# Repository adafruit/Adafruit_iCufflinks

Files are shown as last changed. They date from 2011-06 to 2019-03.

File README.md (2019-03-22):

# iCufflinks

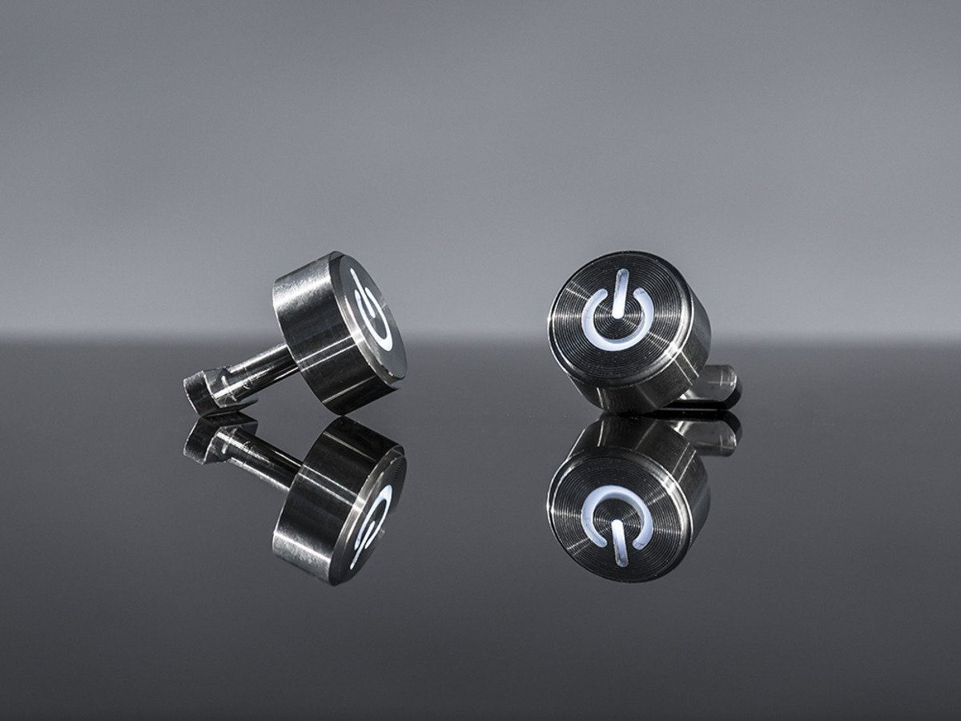
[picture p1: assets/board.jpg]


Sophisticated. Modern. Open Source. Gorgeously machined aluminum with a subtle pulsating LED. Perfect for Father's day or for that geek who loves technology and needs to get dressed up for a special event. Welcome to the future!

This is a new type of product for Adafruit, we want to create wearable electronics that are subtle, fun to wear and look classy. We started with cufflinks and now have a [necklace version](http://www.adafruit.com/products/440) available too.

The cufflinks are CNC machined from the finest 6 series aluminum for durability and beauty. The iCufflinks are a remarkable accessory. Machined with a "screw in backing". Each iCufflink contains a circuit board with pulsating LED and battery.

### Reverse engineered
The "pulsing" is similar to the "breathing" LED pattern on many laptop and computer systems. The default pattern is [reverse engineered](http://www.adafruit.com/blog/2010/08/26/reverse-engineering-the-mac-breathing-led-2/) from the Apple "breathing" LED on Macs, MacBooks, iMacs, etc.

### Open source
Cufflinks are completely open source. [The source code, circuit board files, schematics and CAD files are posted on GitHub. Mod & Hack away! Cufflinks can be reprogrammed to any pattern you'd like!](https://github.com/adafruit/iCufflinks).

### Ready to go
Before your fancy event, just pop the battery in, screw the backing and your iCufflinks will gently pulsate for up to 72 hours. Each order comes with 2 sets of batteries, simply replace them when the LED is too dim to see. We sell replacement batteries as well.

### Designed and made in North America
Cufflinks are lovingly machined in Toronto, Canada by Ross + Doell, assembled in New York, New York USA. Created by Mike Doell, Limor Fried and Phillip Torrone.

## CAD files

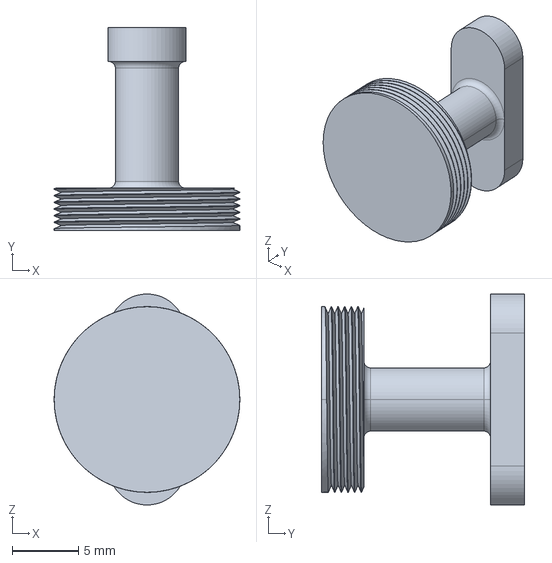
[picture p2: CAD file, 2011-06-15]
CAD/cufflink_back_02.stp
14.0 x 15.2 x 15.9 mm

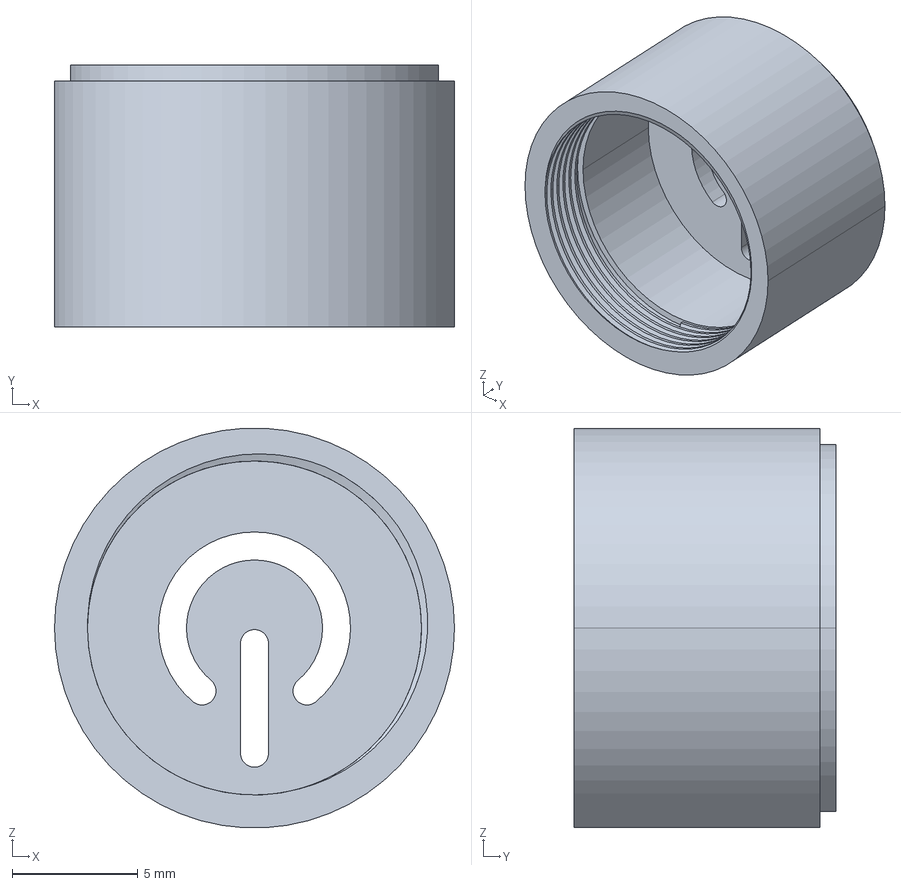
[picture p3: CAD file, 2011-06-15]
CAD/cuffllink_bezel_01.stp
15.9 x 10.4 x 15.9 mm

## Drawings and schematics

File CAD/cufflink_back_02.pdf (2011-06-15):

.55

# SCALE 1.000

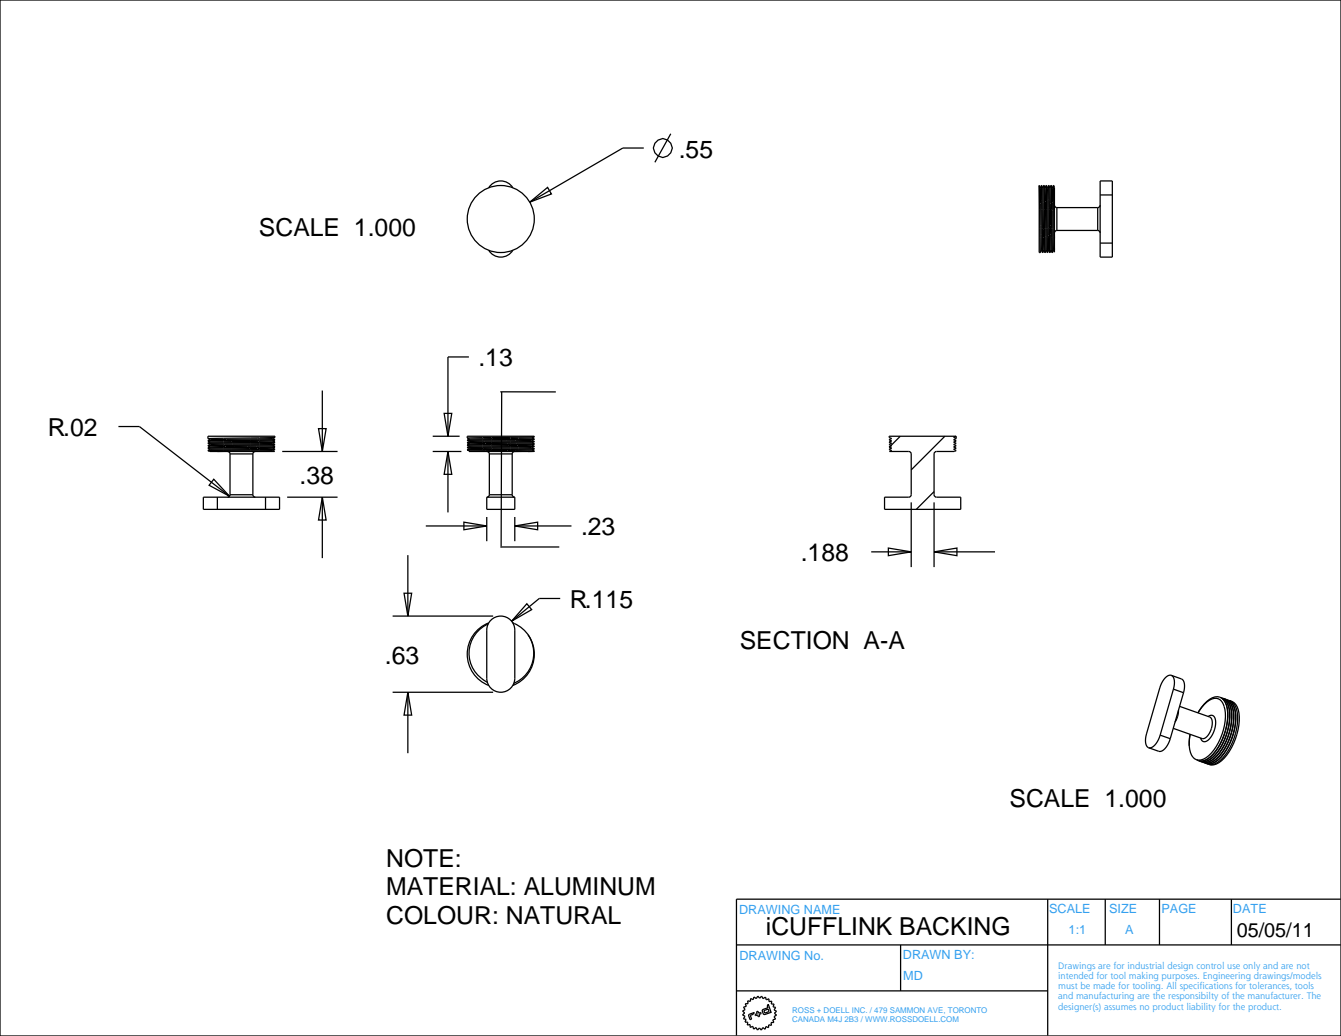
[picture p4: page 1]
NOTE: MATERIAL: ALUMINUM COLOUR: NATURAL; SCALE 1.000; SECTION A-A

DRAWING NAME iCUFFLINK BACKING | SCALE 1:1 | SIZE A | PAGE | DATE 05/05/11

DRAWING No. | DRAWN BY: MD | Drawings are for industrial design control use only and are not intended for tool making purposes. Engineering drawings/models must be made for tooling. All specifications for tolerances, tools and manufacturing are the responsibilty of the manufacturer. The designer(s) assumes no product liability for the product.

ROSS + DOELL INC. / 479 SAMMON AVE, TORONTO
CANADA M4J 2B3 / WWW.ROSSDOELL.COM

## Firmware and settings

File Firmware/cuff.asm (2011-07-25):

.include "tn4def.inc"

.equ    LED = 0				; LED connected to PB0

.cseg
.org 0x0000
	rjmp RESET
.org 0x0008
	rjmp WDT

.def	temp   		= R16	; general purpose temp

RESET:
	sbi DDRB, LED ; LED output
	sbi PORTB, LED ; LED off

	; setting all pullups on unused pins (for power savings)
	; would having them all be outputs use less power?
	ldi temp, (1<<PUEB3)|(1<<PUEB2)|(1<<PUEB1)
	out PUEB, temp

	; changing clock prescale to slow down the processing power 
	; (for power savings)
	; this affects the PWM frequency so if you go too low
	; it may look a little flickery.
	ldi		temp, 0xD8		; write signature
	out		CCP, temp
	; scale to divide by 32. So 8Mhz -> 256kHz
	ldi temp, (0<<CLKPS3)|(1<<CLKPS2)|(0<<CLKPS1)|(1<<CLKPS0) 
	out		CLKPSR, temp

	; set up fast PWM output timer WGM[3:0] = 0101
	; COM0A1 = 1, COM0A0 = 0 or 1
	ldi temp, 0xC1			; Fast PWM (PB2 output)
	out TCCR0A, temp
	ldi temp, 0x81			; fastest clock
	out TCCR0B, temp

	; we dont use the top of the counter since its only 8 bit
	ldi temp, 0
	out OCR0AH, temp

	; enable sleep mode
	ldi temp, (1<<SE) ; by default the mode is 000 Idle
	out SMCR, temp

	sei		; enable global interrupts

LOOPSTART:

	; This is start of Code in Tiny4/5/9/10 (0x4000)
	ldi ZH,	high(SINETAB*2) + 0x40 
	ldi ZL, low (SINETAB*2) ; init Z-pointer to storage bytes
LOOP:
	ld		temp, Z+ ; load next led brightness
	cpi		temp, 0			; last entry?
	brne	NORELOAD
    rjmp    LOOPSTART

NORELOAD:
	out OCR0AL, temp ; Shove the brightness into the PWM driver

	; we want to sleep 6k cycles to match the timing so sleep twice!
	ldi temp, 0xD8		; write signature
	out CCP, temp
	; set watchdog in interrupt mode and 2k cycles
	ldi temp, (0<<WDE)|(1<<WDIE)
	out WDTCSR, temp

	; reset the watchdog timer to full value and sleep until it pops an interrupt
	wdr
	sleep

	ldi temp, 0xD8		; write signature
	out CCP, temp
	; set watchdog in interrupt mode and 4k cycles
	ldi temp, (0<<WDE)|(1<<WDIE)|(1<<WDP0) 
	out WDTCSR, temp

	; reset the watchdog timer to full value and sleep until it pops an interrupt
	wdr
	sleep

	rjmp	LOOP

; this is a do nothing interrupt handler for the watchdog interrupt
WDT:
	reti

SINETAB:
.db 1, 1, 2, 3, 5, 8, 11, 15, 20, 25, 30, 36, 43, 49, 56, 64, 72, 80, 88, 97, 105, 114, 123, 132, 141, 150, 158, 167, 175, 183, 191, 199, 206, 212, 219, 225, 230, 235, 240, 244, 247, 250, 252, 253, 254, 255, 254, 253, 252, 250, 247, 244, 240, 235, 230, 225, 219, 212, 206, 199, 191, 183, 175, 167, 158, 150, 141, 132, 123, 114, 105, 97, 88, 80, 72, 64, 56, 49, 43, 36, 30, 25, 20, 15, 11, 8, 5, 3, 2, 1, 0

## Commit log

2011-06-15 First commit of release!
    [cuff.brd, cuff.sch]
2011-06-15 initial commit of cad STEP files
    [cufflink_back_02.stp, cuffllink_bezel_01.stp]
2011-07-18 This is a test of using the watchdog timer as an interrupt instead of the CPU counter loop for the delay between PWM value switches. This is not tested as I don't have a ATTiny4 to play with but it c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
2011-07-19 enable global interrupts
2011-07-22 removed the unused delay variables that I forgot to take out on the last commit. Adding in two more power savings tricks.
2011-07-24 low power version (integrates commits of @scott-42)
2011-07-24 Revert "changed the clock divider to 64 so now running at 128kHz"
    This reverts commit e72e54e11c92a2d4368831213a4a51ae9d16a79d.
    [cuff.asm]
2011-07-24 Revert "merging back to the main truck so I can have a clean place to make more changes from."
    This reverts commit 2d4b3490d304a5e5d60932b17133d35806b68d6f.
    [cuff.asm]
2011-07-25 tweaked clock speed again to make PWM nice n smooth
